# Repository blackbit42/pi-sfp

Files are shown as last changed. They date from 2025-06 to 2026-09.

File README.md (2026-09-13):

# Raspberry Pi SFP Programmer
This is a [KiCad](https://www.kicad.org/) PCB that makes a [Raspberry Pi](https://www.raspberrypi.com/) hat which allows you to read and write the EEPROM content of a [SFP(+) module](https://en.wikipedia.org/wiki/Small_Form-factor_Pluggable).

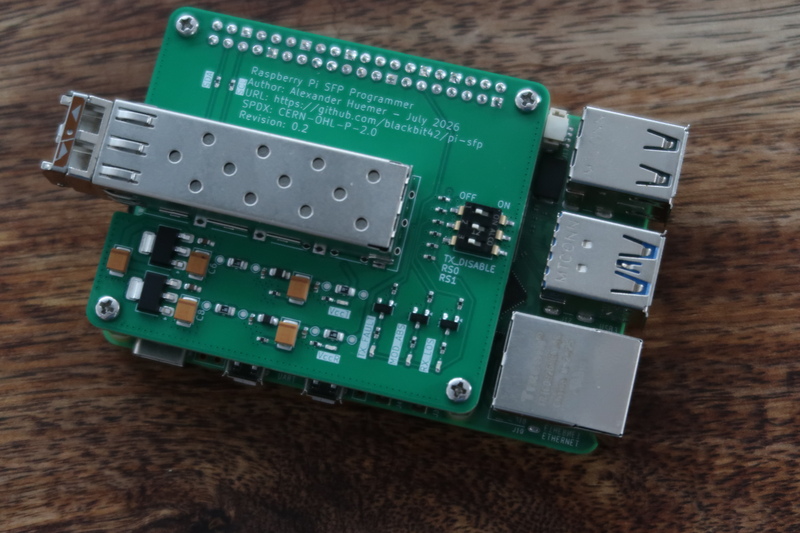
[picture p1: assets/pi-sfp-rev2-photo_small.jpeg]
Raspberry Pi SFP Programmer Photo


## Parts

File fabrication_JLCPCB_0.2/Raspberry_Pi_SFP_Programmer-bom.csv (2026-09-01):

Reference | JLCPCB Part # | Qty | Value | DNP | Exclude from BOM | Exclude from Board | Footprint | Datasheet
U1,U2 | C6186 | 2 | AMS1117-3.3 |  |  |  | Package_TO_SOT_SMD:SOT-223-3_TabPin2 | http://www.advanced-monolithic.com/pdf/ds1117.pdf
Q1,Q2,Q3 | C8664 | 3 | BC847 |  |  |  | Package_TO_SOT_SMD:SOT-23 | http://www.infineon.com/dgdl/Infineon-BC847SERIES_BC848SERIES_BC849SERIES_BC850SERIES-DS-v01_01-en.pdf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
R21,R22 | C17168 | 2 | 0 |  |  |  | Resistor_SMD:R_0402_1005Metric_Pad0.72x0.64mm_HandSolder | ~
R7,R10,R16,R19,R20 | C25936 | 5 | 3.3k |  |  |  | Resistor_SMD:R_0402_1005Metric_Pad0.72x0.64mm_HandSolder | ~
R1,R2,R3,R4,R5,R6,R8,R9,R15 | C60490 | 9 | 10k |  |  |  | Resistor_SMD:R_0402_1005Metric_Pad0.72x0.64mm_HandSolder | ~
C1,C3,C6,C8,C14 | C110051 | 5 | 22u |  |  |  | Capacitor_Tantalum_SMD:CP_EIA-3528-21_Kemet-B_HandSolder | ~
L1,L2 | C285965 | 2 | 4.7u |  |  |  | Inductor_SMD:L_0805_2012Metric_Pad1.05x1.20mm_HandSolder | ~
R12,R13 | C423160 | 2 | 0.5 |  |  |  | Resistor_SMD:R_0402_1005Metric_Pad0.72x0.64mm_HandSolder | ~
C12,C13 | C519560 | 2 | 1u |  |  |  | Capacitor_SMD:C_0603_1608Metric_Pad1.08x0.95mm_HandSolder | ~
C2,C4,C5,C7 | C913742 | 4 | 0.1u |  |  |  | Capacitor_SMD:C_0402_1005Metric_Pad0.74x0.62mm_HandSolder | ~
R11,R14,R17,R18 | C2074770 | 4 | 0.1 |  |  |  | Resistor_SMD:R_0805_2012Metric_Pad1.20x1.40mm_HandSolder | ~
D1,D2,D3,D4,D5 | C5123485 | 5 | LED |  |  |  | LED_SMD:LED_0402_1005Metric_Pad0.77x0.64mm_HandSolder | ~
SW1 | C5727991 | 1 | EDS03SGNNTR04Q |  |  |  | Raspberry_Pi_SFP_Programmer:SW_2319847_TEC | EDS03SGNNTR04Q
J2 | C42931381 | 1 | SFP+ |  |  |  | Connector:Connector_SFP_and_Cage | https://members.snia.org/document/dl/25892

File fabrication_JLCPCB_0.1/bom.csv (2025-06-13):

Designator | Footprint | Quantity | Value | LCSC Part #
C1 | 0402 | 1 | 1u
D1, D2 | 0402 | 2 | LED
J1 | RPI_Hat_B+ | 1 | RPi_GPIO
J2 | Connector_SFP_and_Cage | 1 | SFP+
J4 | PinHeader_2x03_P2.54mm_Vertical | 1 | Conn_02x03_Odd_Even
Q1, Q2 | SOT-23 | 2 | BC847
R1, R2, R3, R4, R5, R6, R8, R9 | 0402 | 8 | 10k
R10, R7 | 0402 | 2 | 330

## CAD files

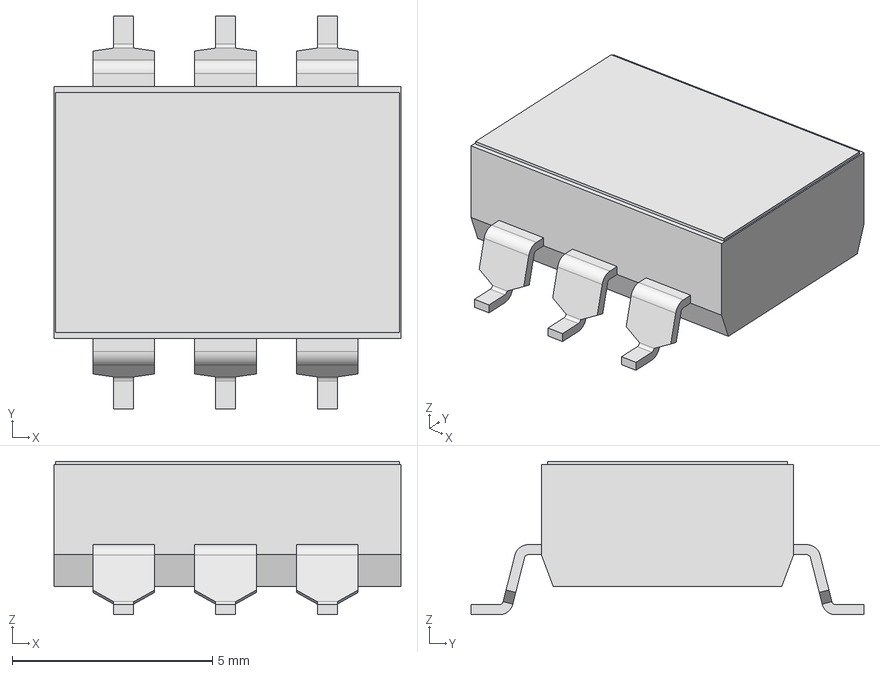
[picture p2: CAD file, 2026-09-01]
Raspberry_Pi_SFP_Programmer.3dmodels/KAE03TGGx.stp
8.66 x 9.80 x 3.83 mm

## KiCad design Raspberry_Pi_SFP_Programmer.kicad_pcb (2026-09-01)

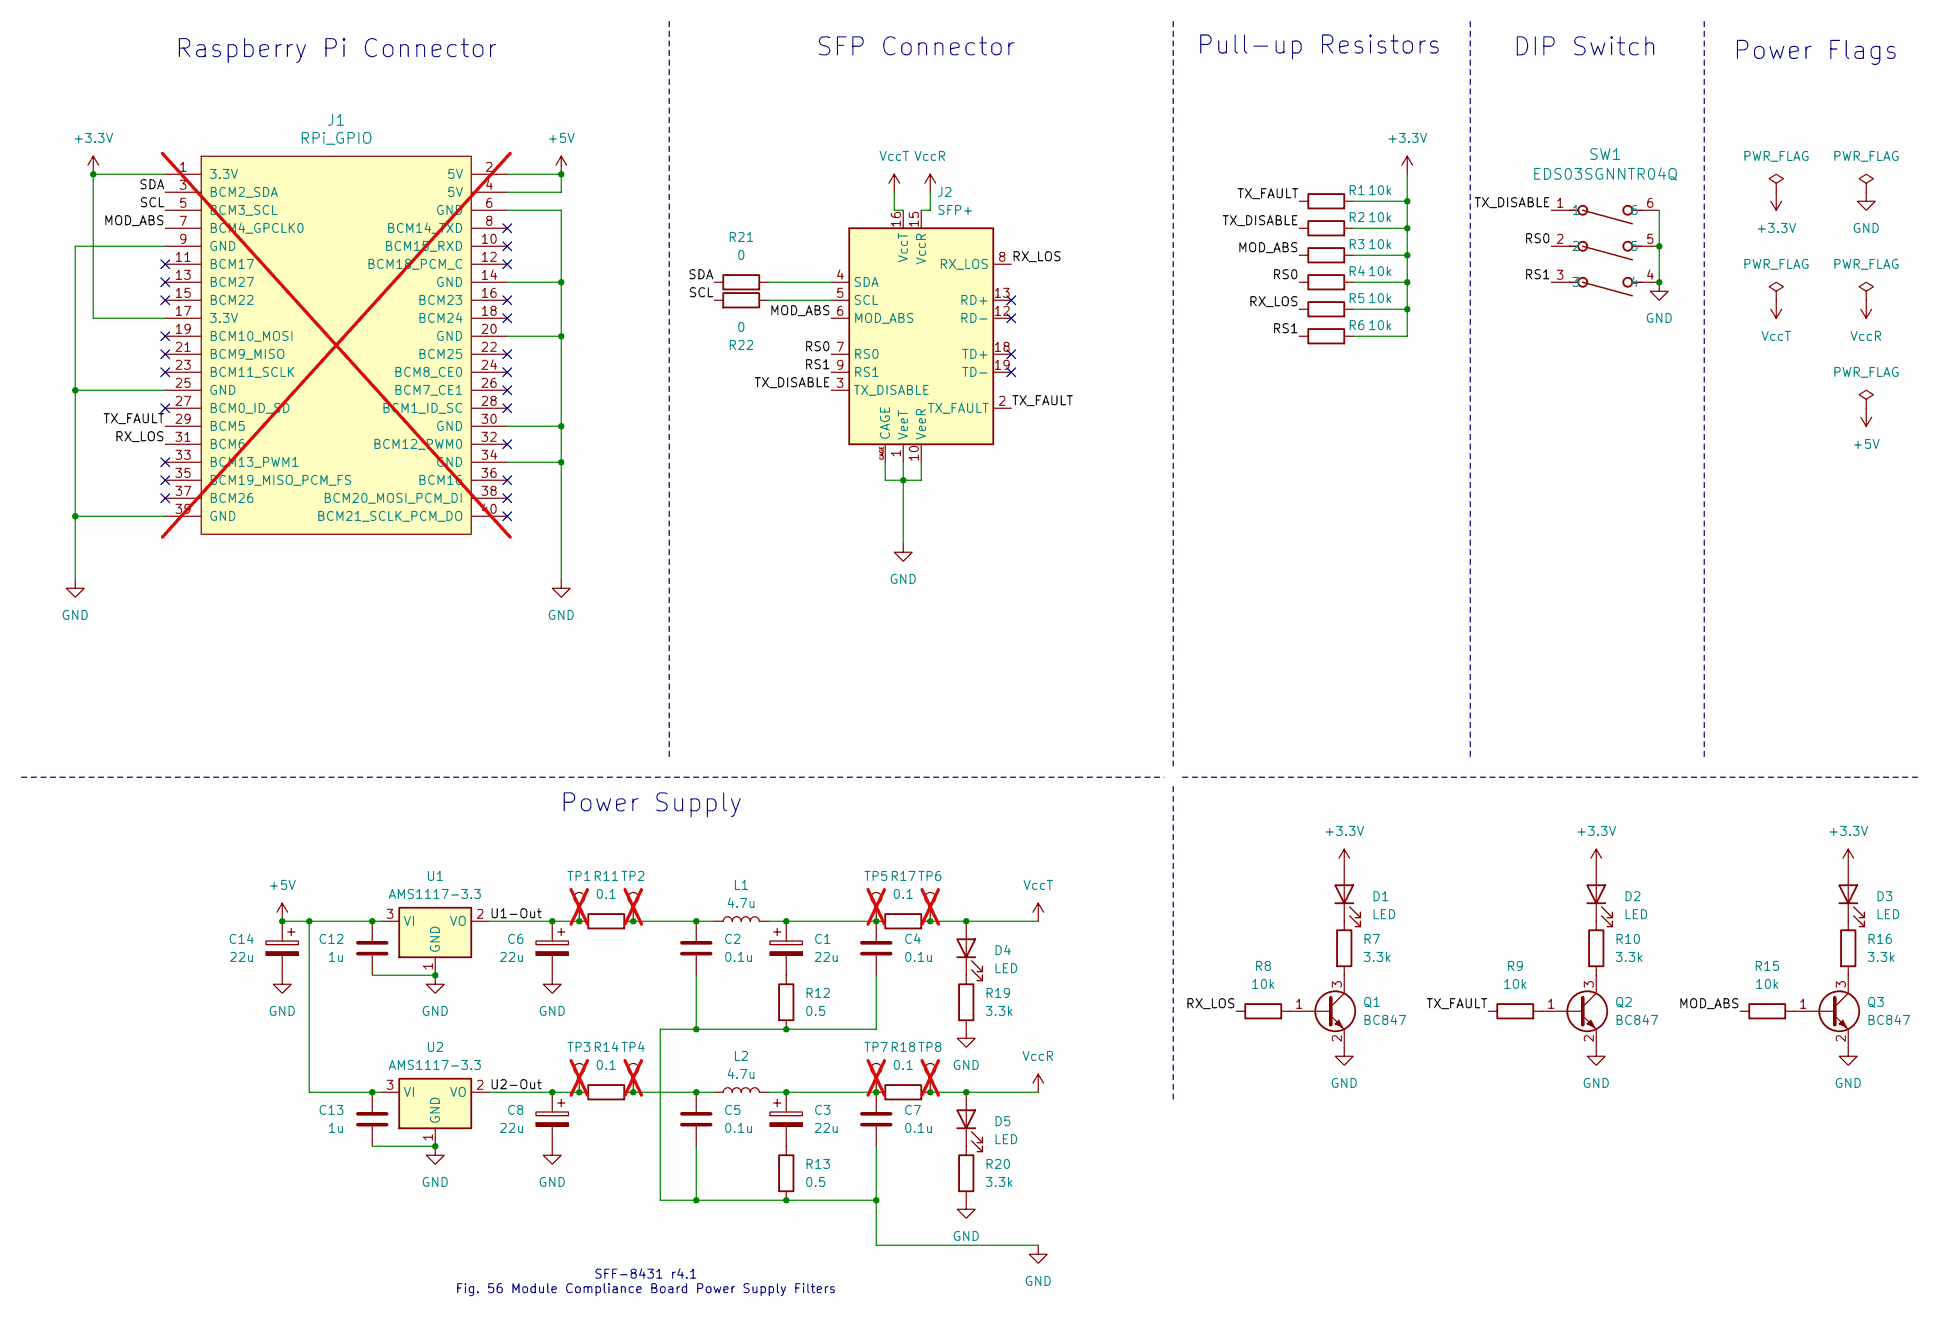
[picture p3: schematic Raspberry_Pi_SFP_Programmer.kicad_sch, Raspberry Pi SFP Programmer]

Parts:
C1, C3, C6, C8, C14: 22u; CP_EIA-3528-21_Kemet-B_HandSolder; JLCPCB Part # C110051
C2, C4, C5, C7: 0.1u; C_0402_1005Metric_Pad0.74x0.62mm_HandSolder; JLCPCB Part # C913742
C12, C13: 1u; C_0603_1608Metric_Pad1.08x0.95mm_HandSolder; JLCPCB Part # C519560
D1, D2, D3, D4, D5: LED; LED_0402_1005Metric_Pad0.77x0.64mm_HandSolder; JLCPCB Part # C5123485
J1: RPi_GPIO; RPI_Hat_B+; not fitted
J2: SFP+; Connector_SFP_and_Cage; JLCPCB Part # C42931381
L1, L2: 4.7u; L_0805_2012Metric_Pad1.05x1.20mm_HandSolder; JLCPCB Part # C285965
Q1, Q2, Q3: BC847; SOT-23; JLCPCB Part # C8664
R1, R2, R3, R4, R5, R6, R8, R9, R15: 10k; R_0402_1005Metric_Pad0.72x0.64mm_HandSolder; JLCPCB Part # C60490
R7, R10, R16, R19, R20: 3.3k; R_0402_1005Metric_Pad0.72x0.64mm_HandSolder; JLCPCB Part # C25936
R11, R14, R17, R18: 0.1; R_0805_2012Metric_Pad1.20x1.40mm_HandSolder; JLCPCB Part # C2074770
R12, R13: 0.5; R_0402_1005Metric_Pad0.72x0.64mm_HandSolder; JLCPCB Part # C423160
R21, R22: 0; R_0402_1005Metric_Pad0.72x0.64mm_HandSolder; JLCPCB Part # C17168
SW1: EDS03SGNNTR04Q; SW_2319847_TEC; JLCPCB Part # C5727991
TP1, TP2, TP3, TP4, TP5, TP6, TP7, TP8: TestPoint; TestPoint_Pad_D1.0mm; not fitted
U1, U2: AMS1117-3.3; SOT-223-3_TabPin2; JLCPCB Part # C6186

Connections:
+3.3V: D1.2 (A), D2.2 (A), D3.2 (A), J1.1 (3.3V), J1.17 (3.3V), R1.2, R2.2, R3.2, R4.2, R5.2, R6.2
+5V: C12.2, C13.2, C14.1, J1.2 (5V), J1.4 (5V), U1.3 (VI), U2.3 (VI)
/MOD_ABS: J1.7 (BCM4_GPCLK0), J2.6 (MOD_ABS), R3.1, R15.1
/RS0: J2.7 (RS0), R4.1, SW1.2
/RS1: J2.9 (RS1), R6.1, SW1.3
/RX_LOS: J1.31 (BCM6), J2.8 (RX_LOS), R5.1, R8.1
/SCL: J1.5 (BCM3_SCL), R22.2
/SDA: J1.3 (BCM2_SDA), R21.1
/TX_DISABLE: J2.3 (TX_DISABLE), R2.1, SW1.1
/TX_FAULT: J1.29 (BCM5), J2.2 (TX_FAULT), R1.1, R9.1
/U1-Out: C6.1, R11.1, TP1.1, U1.2 (VO)
/U2-Out: C8.1, R14.1, TP3.1, U2.2 (VO)
GND: C2.2, C4.2, C5.2, C6.2, C7.2, C8.2, C12.1, C13.1, C14.2, J1.6 (GND), J1.9 (GND), J1.14 (GND), J1.20 (GND), J1.25 (GND), J1.30 (GND), J1.34 (GND), J1.39 (GND), J2.1 (VeeT), J2.10 (VeeR), J2.11 (VeeR), J2.14 (VeeR), J2.17 (VeeT), J2.20 (VeeT), J2.CAGE, Q1.2 (E), Q2.2 (E), Q3.2 (E), R12.2, R13.2, R19.2, R20.2, SW1.4, SW1.5, SW1.6, U1.1 (GND), U2.1 (GND)
unnamed: C1.1, C4.1, L1.2, R17.1, TP5.1
unnamed: C1.2, R12.1
unnamed: C2.1, L1.1, R11.2, TP2.1
unnamed: C3.1, C7.1, L2.2, R18.1, TP7.1
unnamed: C3.2, R13.1
unnamed: C5.1, L2.1, R14.2, TP4.1
unnamed: D1.1 (K), R7.1
unnamed: D2.1 (K), R10.1
unnamed: D3.1 (K), R16.1
unnamed: D4.1 (K), R19.1
unnamed: D5.1 (K), R20.1
unnamed: J2.5 (SCL), R22.1
unnamed: J2.4 (SDA), R21.2
unnamed: Q1.1 (B), R8.2
unnamed: Q1.3 (C), R7.2
unnamed: Q2.1 (B), R9.2
unnamed: Q2.3 (C), R10.2
unnamed: Q3.1 (B), R15.2
unnamed: Q3.3 (C), R16.2
VccR: D5.2 (A), J2.15 (VccR), R18.2, TP8.1
VccT: D4.2 (A), J2.16 (VccT), R17.2, TP6.1

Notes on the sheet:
SFP Connector
SFF-8431 r4.1 Fig. 56 Module Compliance Board Power Supply Filters
DIP Switch
Power Flags
Power Supply
Pull-up Resistors
Raspberry Pi Connector

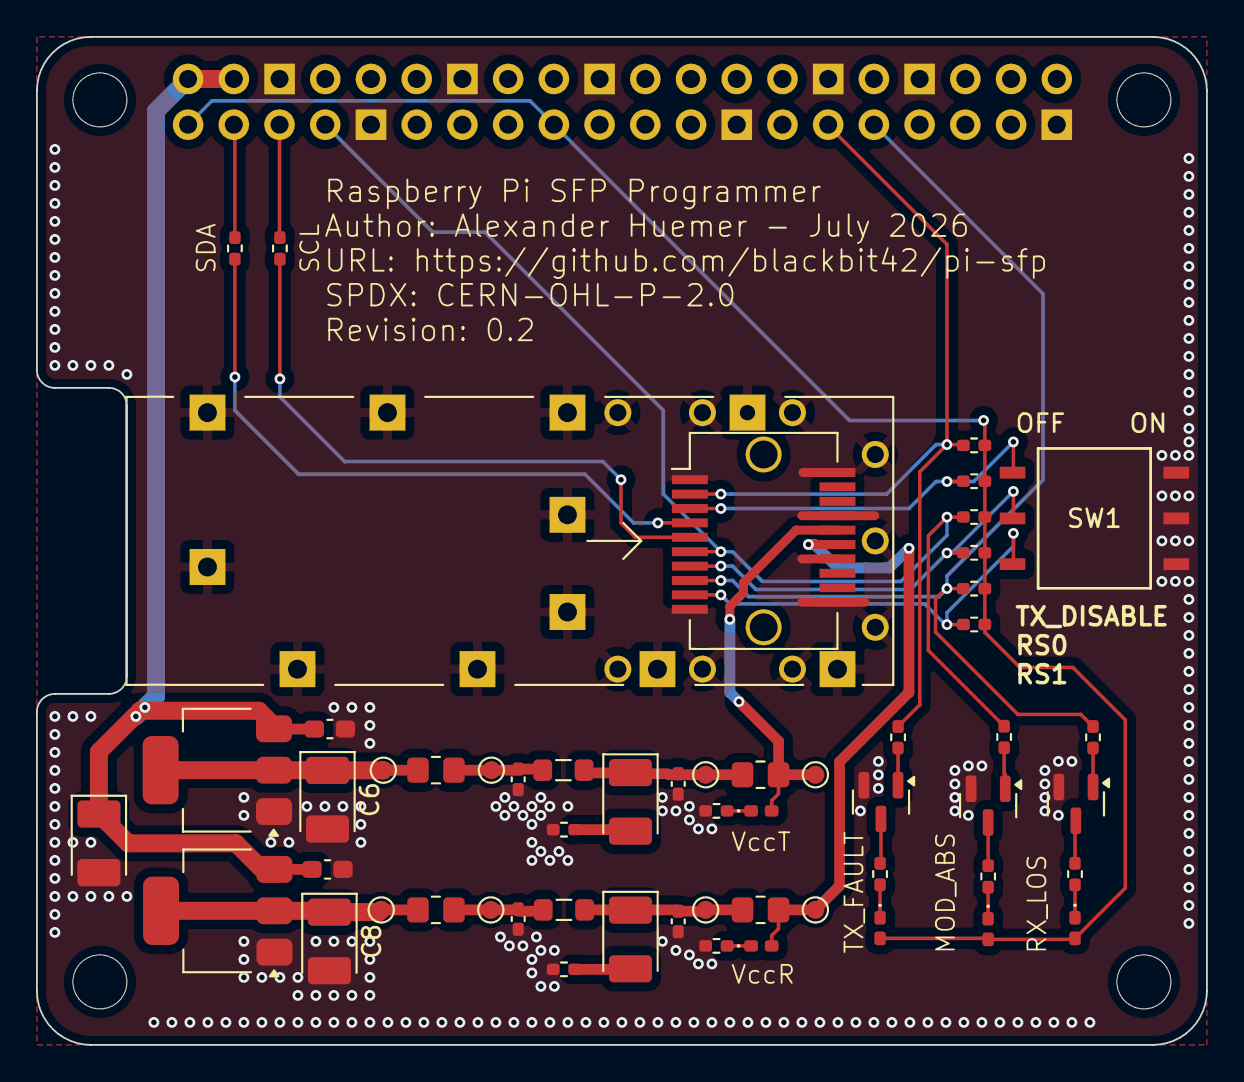
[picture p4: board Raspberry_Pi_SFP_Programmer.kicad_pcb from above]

Board: 2 copper layers, 65.0 x 56.0 mm, 56 parts (0 on the bottom side), 34 nets.

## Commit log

2025-06-13 Rev. 0.1
    [Raspberry_Pi_SFP_Programmer.kicad_pcb, Raspberry_Pi_SFP_Programmer.kicad_sch, bom.csv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]
2025-12-18 Fix PSU cap
    [Raspberry_Pi_SFP_Programmer.kicad_pcb, Raspberry_Pi_SFP_Programmer.kicad_sch]
2026-09-01 Multiple improvements
    Fix 3.3V rail decoupling
    Derive VccT and VccR from 5V
    Add power supply filter networks
    Replace jumper pin header with dip switch
    Add LED for MOD_ABS
    Connect RX_LOS and TX_FAULT to GPIOs
    [KAE03TGGx.stp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]

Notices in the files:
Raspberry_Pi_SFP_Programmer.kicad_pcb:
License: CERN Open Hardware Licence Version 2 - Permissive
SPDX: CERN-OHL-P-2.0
